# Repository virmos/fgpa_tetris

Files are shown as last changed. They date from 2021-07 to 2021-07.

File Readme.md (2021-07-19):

# nand2tetris-FPGA

> ... _Would'nt it be nice to make Hack or Jack also run on some "real platform," made from some "real stuff"?_ ... 
>
>---Noam Nisan and Shimon Schocken

This project is about building Hack on real hardware as proposed in Chapter 13 of the course [nand2tetris](https://www.nand2tetris.org/) using only FOSS, free and open source hard- and software. 

We build hack in 9 steps, starting with Hack-1, a minimal working Hack-CPU connected to some leds and buttons and ending at Hack-9, the final implementation of Hack running Jack-Compiled code with specs:
* original CPU/ALU design of HACK from nand2tetris
* implemented on iCE40 FPGA
* clocked at 33.333333 MHz 
* RAM 3840 x 16 bit (R0-R15/static/stack/heap)
* Programmable instruction memory PROM 64K x 16 bit
* 2.8 Inch Color LCD with 320x240 Pixel
* SD-Card-Reader
* bootloader in ROM (256 words) boots Hack-code from SD or UART
* sound-card capable of playing the tetris theme
* touch-panel support

Finally we will proof, that Hack-9 is powerfull enough to run serious Jack-Application like Pong and Tetris!

## Roadmap

In every project folder/subfolder you find a file `Readme.md` containing specifications and implementation details.

>_... This is your last chance. After this, there is no turning back. You take the blue pill — the story ends, you wake up in your bed and believe whatever you want to believe. You take the red pill — you stay in Wonderland and I show you how deep the rabbit-hole goes. ..._
>
> ---Morpheus

### [Project0: Requirement](00_Requirement)

Get the hardware and install the tools.
### [Project 1: Hack1-minimal](01_Hack1-minimal)
Build minimal running version of Hack-CPU connected to two buttons and two leds as input/output.
### [Project 2: Hack2-UART](02_Hack2-UART)
Add UART support so Hack can send and receive bytes at runtime. First test of Virtual machine running small Jack-compiled programs like `echo`.
### [Project 3: Hack3-SRAM](03_Hack3-SRAM)
Hack writes and reads data to external SRAM-chip so bigger Hack-programms can be stored (64K x 16 bit).
### [Project 4: Hack4-BOOT](04_Hack4-BOOT)
Bootlogic can switch instruction memory between internal ROM (boot-mode) and external SRAM (run-mode).
### [Project 5: Jack-OS](05_Jack-OS)
Hack now has 3840 x 16 bit of RAM for stack/heap, 256 x 16 bit of ROM preloaded with bootloader and 64K x 16 bit of programmable instruction memory. It's time to implement Jack-OS and run application like `Average`.
### [Project 6: Hack6-LCD](06_Hack6-LCD)
Connect Screen MOD-2.8LCD-RTP with 320x240 pixels in 16 bit color depth. Rewrite parts of OS `Screen.jack` and `Output.jack`. Play Pong!



### [Project 7: Hack7-TOUCH](07_Hack7-Touch)
Add support for resistive touch panel of MOD-2.8LCD-RTP. Just because it's there.
### [Project 8: Hack8-SOUND](08_Hack8-Sound)
Build "mini sound-card" capable of playing Tetris-theme.



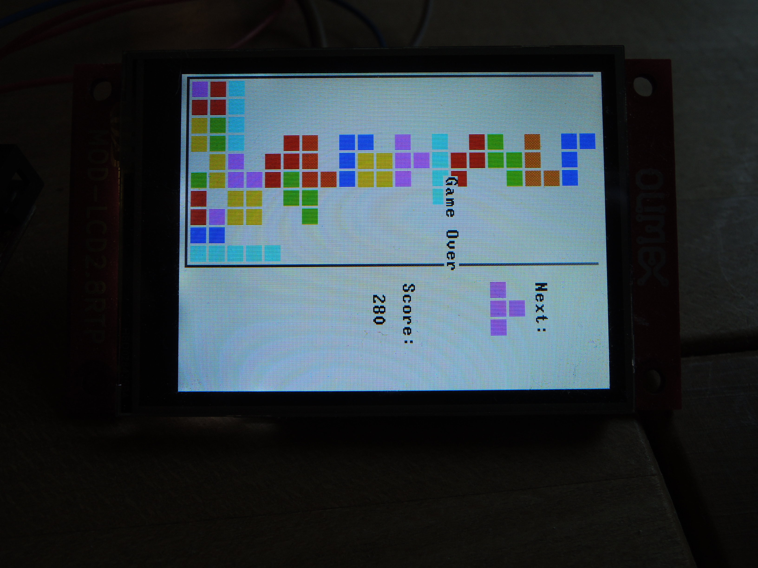
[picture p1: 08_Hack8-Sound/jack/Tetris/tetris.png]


### [Project 9: Hack9-SDCard](09_Hack9-SD)
Add SD-card reader MOD-SDMMC. Reimplement bootloader capable of loading Jack-compiled code from SD-Card directly into SRAM. Play Tetris!

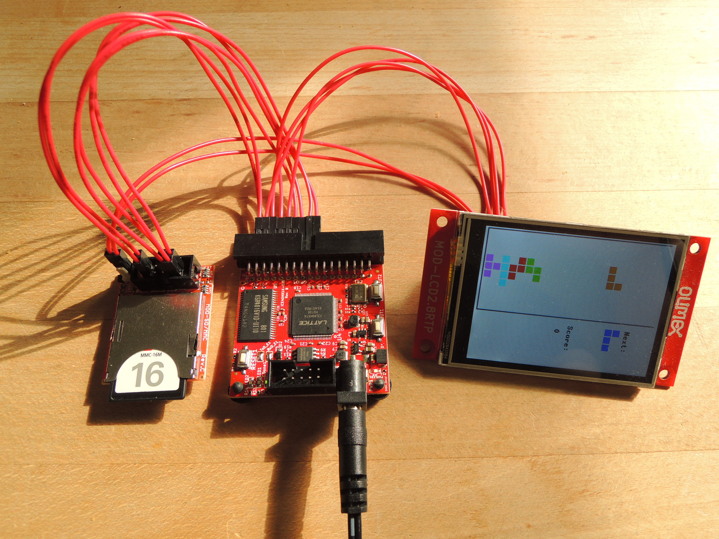
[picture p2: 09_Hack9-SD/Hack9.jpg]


## Credits

* Noam Nisan and Shimon Schocken: Visit [nand2tetris](https://nand2tetris.org) and learn to build a modern general-purpose computer system from ground up.
* [Olimex Ltd](https://www.olimex.com/): Buy your hardware from the Company with highest number of registered OSHW projects :)
* Wolf Clifford: The master of open source FPGA with iCE40 and  [Project IceStorm](http://www.clifford.at/icestorm/)
* Jesús Arroyo Torrens, Juan González (Obijuan): Open source ecosystem for open FPGA boards [APIO](https://github.com/FPGAwars/apio)
* Juan González-Gomez (Obijuan): Lern verilog with [open-fpga-verilog-tutorial](https://github.com/Obijuan/open-fpga-verilog-tutorial/), best tutorial!
* Icons made by <a href="https://www.flaticon.com/free-icon/cpu_483131?term=cpu&page=3&position=86" title="Those Icons">Those Icons</a> from <a href="https://www.flaticon.com/" title="Flaticon"> www.flaticon.com</a>

---
For questions or comments write an email to 
mi.schroeder@netcologne.de

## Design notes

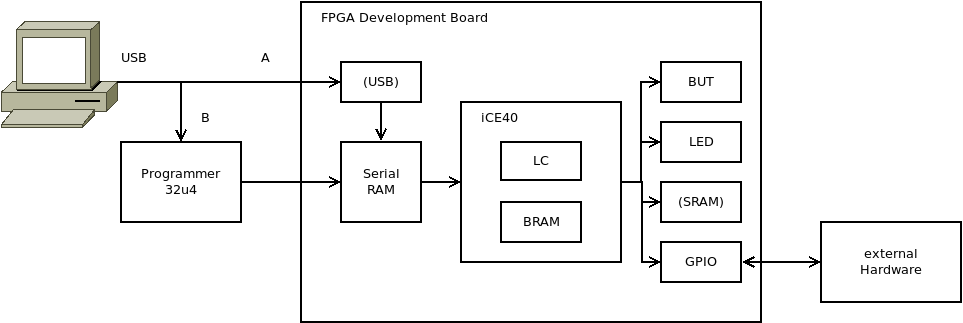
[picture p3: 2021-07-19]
00_Requirement/doc/fpga.png

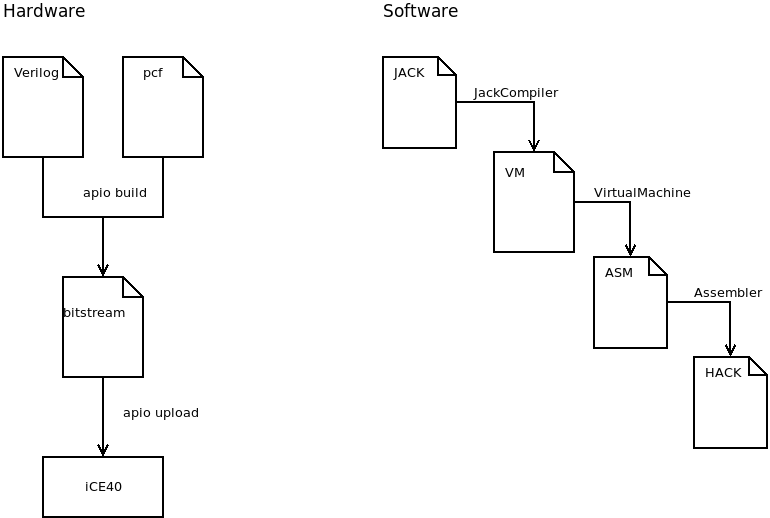
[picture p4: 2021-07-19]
00_Requirement/doc/soft.png

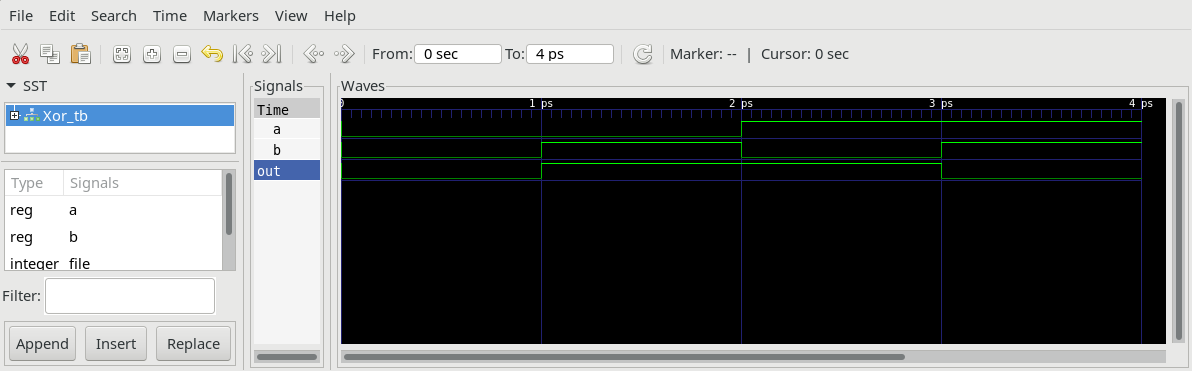
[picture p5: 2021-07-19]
00_Requirement/Xor/Xor.png

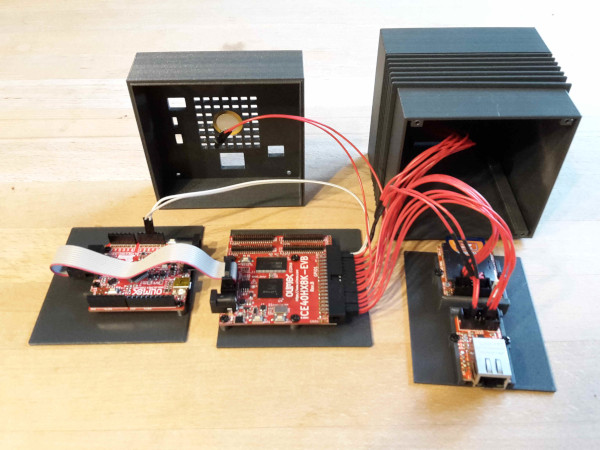
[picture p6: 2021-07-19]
11_Cube/pics/cube_modules.jpg

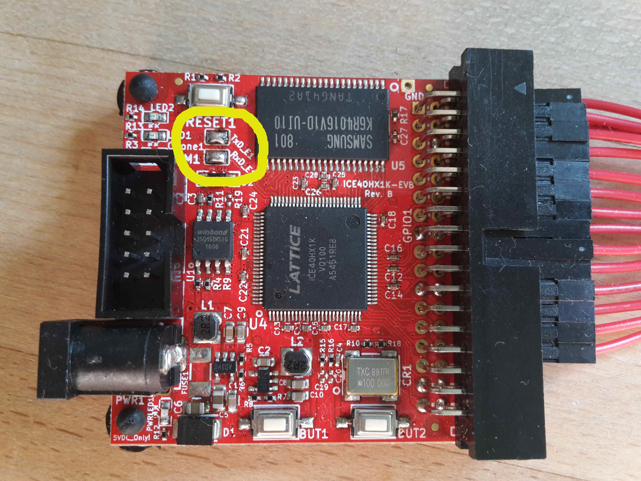
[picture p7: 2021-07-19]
02_Hack2-UART/doc/UARTJumper.jpg

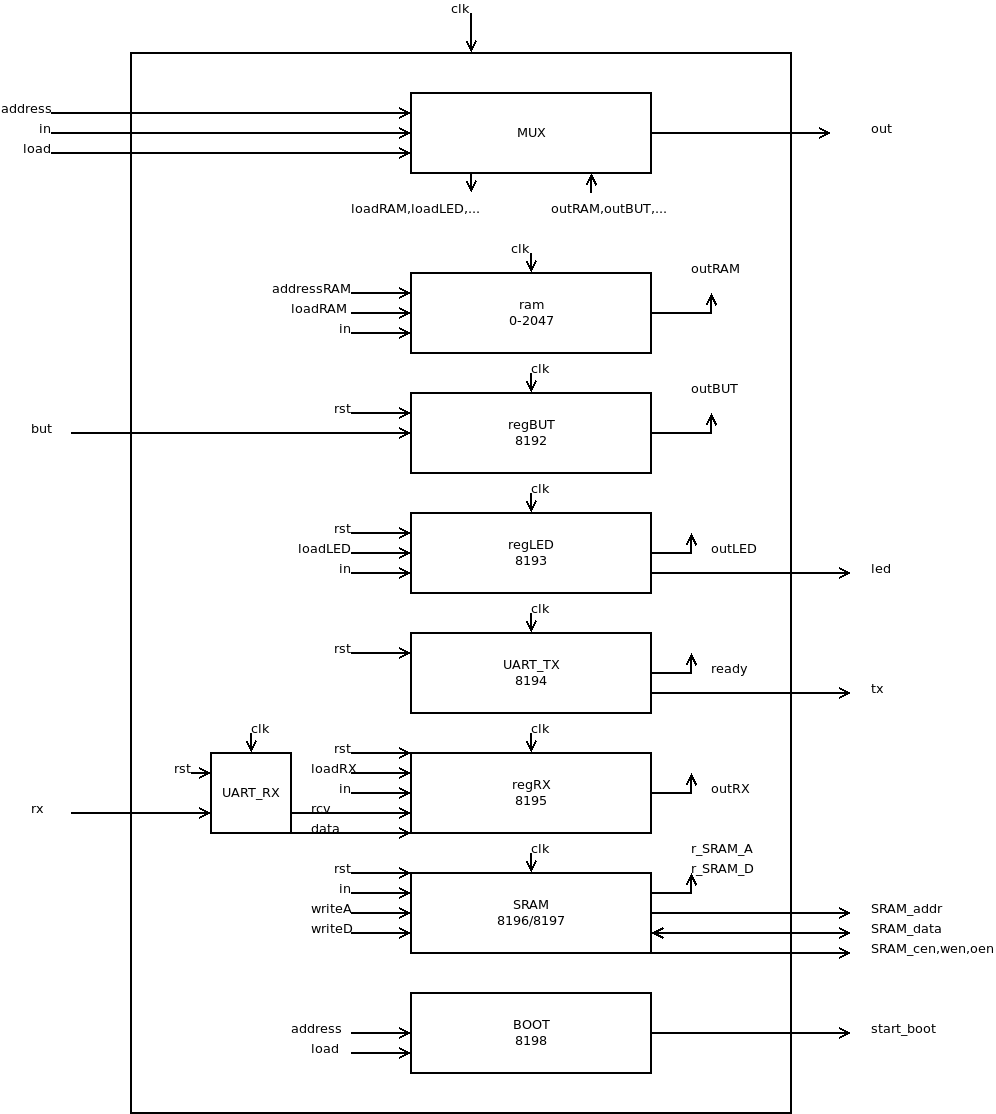
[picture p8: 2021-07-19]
04_Hack4-BOOT/doc/mem.png

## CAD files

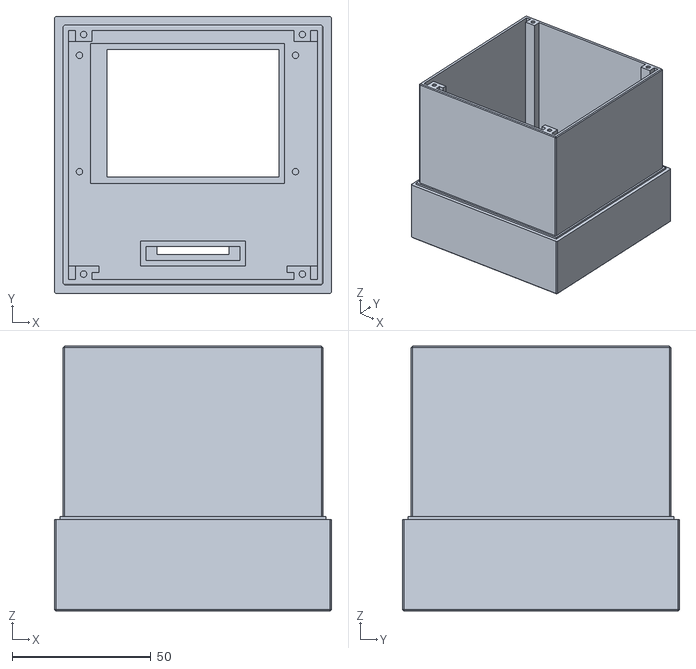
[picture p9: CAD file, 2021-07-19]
11_Cube/files/front-Cube.stl
100.0 x 100.0 x 95.6

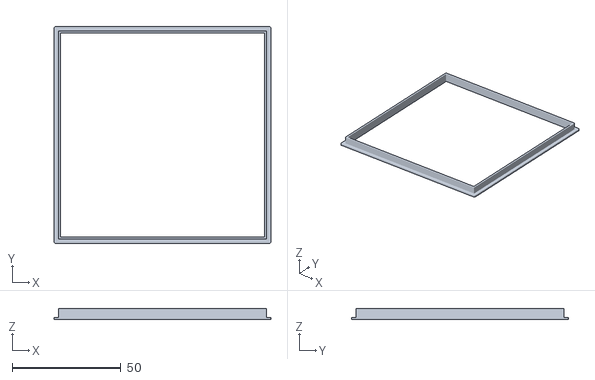
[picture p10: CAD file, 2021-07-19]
11_Cube/files/rip-Cube.stl
100.0 x 100.0 x 5.00

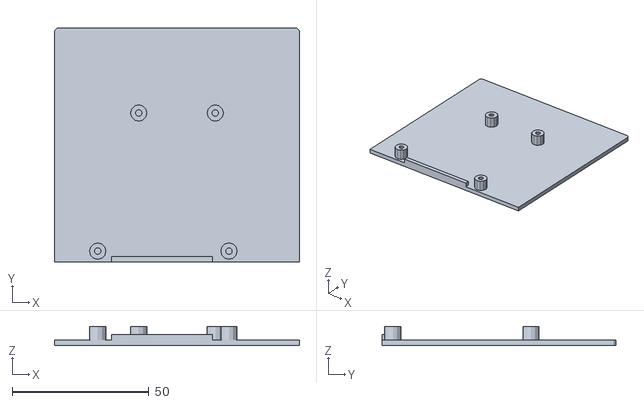
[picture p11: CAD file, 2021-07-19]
11_Cube/files/tray_32u4-Cube.stl
89.6 x 85.6 x 7.00

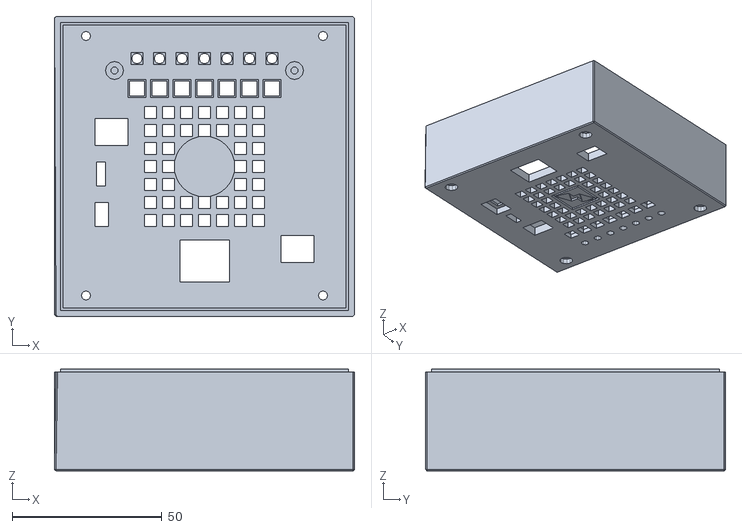
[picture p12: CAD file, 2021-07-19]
11_Cube/files/rear-Cube.stl
100.0 x 100.0 x 34.0

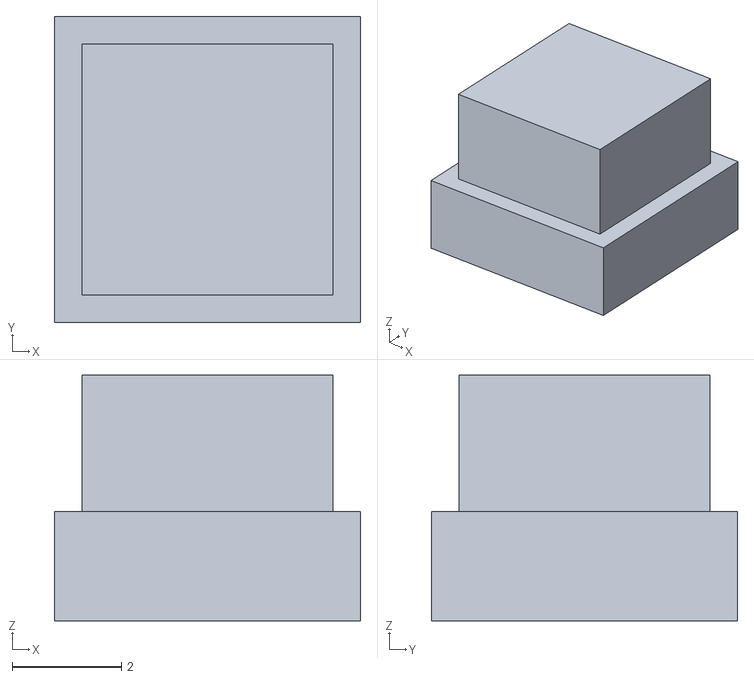
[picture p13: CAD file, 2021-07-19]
11_Cube/files/button-Cube.stl
5.60 x 5.60 x 4.50

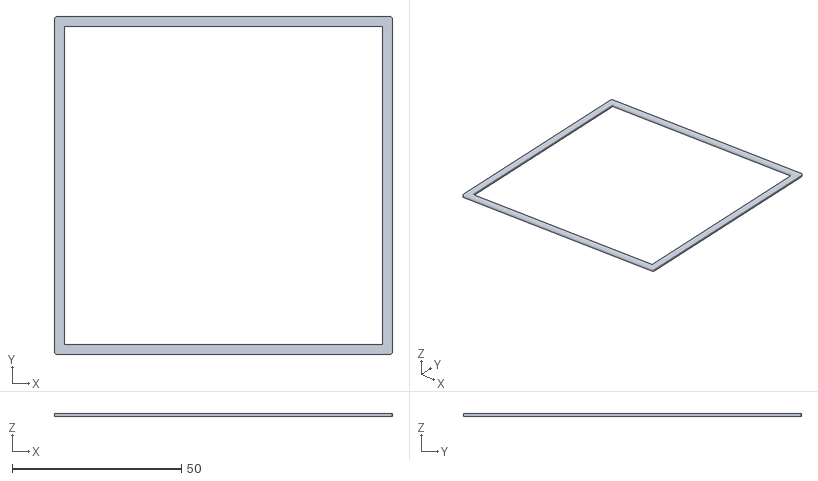
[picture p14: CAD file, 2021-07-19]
11_Cube/files/rip_center-Cube.stl
100.0 x 100.0 x 1.00

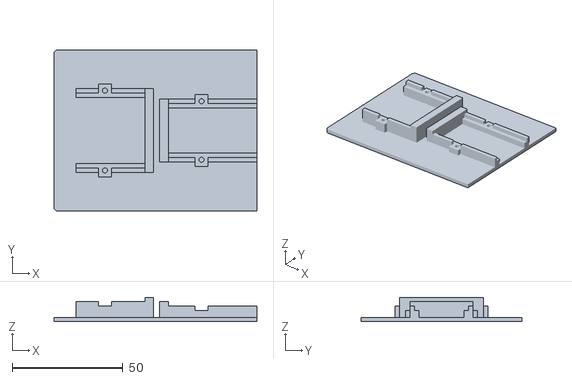
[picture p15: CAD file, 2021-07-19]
11_Cube/files/tray_SD_ETH-Cube.stl
91.6 x 72.6 x 11.0

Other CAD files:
11_Cube/files/tray_ice40-Cube.stl
11_Cube/files/button.blend
11_Cube/files/cube.blend
11_Cube/files/front.blend
11_Cube/files/nothing.blend
11_Cube/files/rear.blend
11_Cube/files/rip.blend
11_Cube/files/rip_center.blend
11_Cube/files/tray_32u4.blend
11_Cube/files/tray_SD_ETH.blend
11_Cube/files/tray_ice40.blend

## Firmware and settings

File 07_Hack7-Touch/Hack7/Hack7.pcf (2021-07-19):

# physical constrain file
# assign io-pins to pin numbering of iCE40-HX1K on olimex board iCE40-HX1K-EVB
# compare to the schematic of the board and the datasheet of fpga

set_io clk_in 15				
set_io -pullup yes but[0] 41	
set_io -pullup yes but[1] 42
set_io -pullup yes but[2] 34
set_io -pullup yes but[3] 33
set_io -pullup yes but[4] 30
set_io -pullup yes but[5] 29
set_io -pullup yes but[6] 28
set_io -pullup yes but[7] 27

set_io led[0] 40
set_io led[1] 51
set_io led[2] 26
set_io led[3] 25
set_io led[4] 24
set_io led[5] 21
set_io led[6] 20
set_io led[7] 19

set_io rx 36		# UEXT
set_io tx 37		# UEXT

set_io sram_addr[0] 79
set_io sram_addr[1] 80
set_io sram_addr[2] 81
set_io sram_addr[3] 82
set_io sram_addr[4] 83
set_io sram_addr[5] 85
set_io sram_addr[6] 86
set_io sram_addr[7] 87
set_io sram_addr[8] 89
set_io sram_addr[9] 90
set_io sram_addr[10] 91
set_io sram_addr[11] 93
set_io sram_addr[12] 94
set_io sram_addr[13] 95
set_io sram_addr[14] 96
set_io sram_addr[15] 97
set_io sram_addr[16] 99
set_io sram_addr[17] 100

set_io sram_cen 78
set_io sram_oen 74
set_io sram_wen 73

set_io sram_data[0] 62
set_io sram_data[1] 63
set_io sram_data[2] 64
set_io sram_data[3] 65
set_io sram_data[4] 66
set_io sram_data[5] 68
set_io sram_data[6] 69
set_io sram_data[7] 71
set_io sram_data[8] 72
set_io sram_data[9] 60
set_io sram_data[10] 59
set_io sram_data[11] 57
set_io sram_data[12] 56
set_io sram_data[13] 54
set_io sram_data[14] 53
set_io sram_data[15] 52

set_io lcd_dcn 1
set_io lcd_mosi 2
set_io lcd_sck 3
set_io lcd_cen 4

set_io tp_miso 7
set_io tp_mosi 8
set_io tp_sck 9

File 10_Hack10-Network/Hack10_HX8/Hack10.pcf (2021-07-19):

# physical constrain file
# assign io-pins to pin numbering of iCE40-HX1K on olimex board iCE40-HX1K-EVB
# compare to the schematic of the board and the datasheet of fpga
# to use internal pullup set (-pullup yes)

set_io clk_in J3				
set_io but[0] K11 # BUT1 on board
set_io but[1] P13 # BUT2 on board
set_io but[2] J4 # GPIO 20
set_io but[3] H2 # GPIO 18
set_io but[4] J5 # GPIO 16
set_io but[5] G1 # GPIO 14
set_io but[6] H1 # GPIO 12
set_io but[7] J2 # GPIO 10

set_io led[0] M12 # LED1 on board
set_io led[1] R16 # LED2 on board
set_io led[2] H3 # GPIO 32
set_io led[3] F2 # GPIO 30
set_io led[4] H6 # GPIO 28
set_io led[5] F1 # GPIO 26
set_io led[6] H4 # GPIO 24
set_io led[7] G2 # GPIO 22

set_io rx L11	# UEXT
set_io tx T16	# UEXT

set_io sram_addr[0] N6
set_io sram_addr[1] T1
set_io sram_addr[2] P4
set_io sram_addr[3] R2
set_io sram_addr[4] N5
set_io sram_addr[5] T2
set_io sram_addr[6] P5
set_io sram_addr[7] R3
set_io sram_addr[8] R5
set_io sram_addr[9] T3
set_io sram_addr[10] R4
set_io sram_addr[11] M7
set_io sram_addr[12] N7
set_io sram_addr[13] P6
set_io sram_addr[14] M8
set_io sram_addr[15] T5
set_io sram_addr[16] R6
set_io sram_addr[17] P8

set_io sram_cen T6
set_io sram_oen L9
set_io sram_wen T7

set_io sram_data[0] T8
set_io sram_data[1] P7
set_io sram_data[2] N9
set_io sram_data[3] T9
set_io sram_data[4] M9
set_io sram_data[5] R9
set_io sram_data[6] K9
set_io sram_data[7] P9
set_io sram_data[8] R10
set_io sram_data[9] L10
set_io sram_data[10] P10
set_io sram_data[11] N10
set_io sram_data[12] T10
set_io sram_data[13] T11
set_io sram_data[14] T15
set_io sram_data[15] T14

set_io lcd_dcn E4
set_io lcd_mosi B2
set_io lcd_sck F5
set_io lcd_cen B1

set_io tp_miso C1
set_io tp_mosi C2
set_io tp_sck F4

set_io snd D2

set_io sd_miso G5
set_io sd_mosi D1
set_io sd_sck G4
set_io sd_cen E3

set_io eth_miso H5
set_io eth_mosi E2
set_io eth_sck G3
set_io eth_cs F3
